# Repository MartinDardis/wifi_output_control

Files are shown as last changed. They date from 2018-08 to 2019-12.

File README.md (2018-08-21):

# Control de salidas - ESP8266 WiFi

## Caracteristicas Generales:

* Modo Station o Access Point automatico
* Soporte ARDUINO OTA y WEB OTA (update con firm.bin)
* Configuracion red WiFi y Login almacenada en memoria flash.
* Soporta hasta 2 salidas en simultaneo (PCB para 1 o 2).

## Diagrama de Cableado

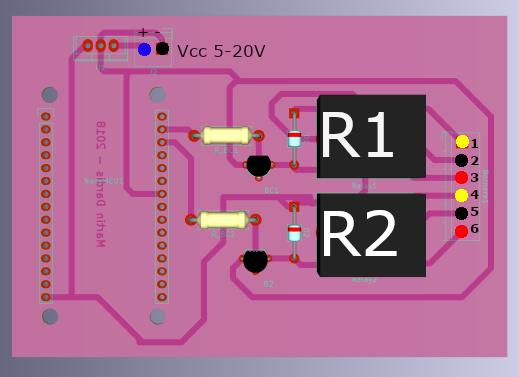
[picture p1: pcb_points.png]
PCB


Los pines **1,2,3** pertenecen al relay 1, donde 2 (NEGRO) es la entrada, 1 (AMARILLO) es la salida normal cerrada y 3 (ROJO) la normal abierta.

Los pines **4,5,6** pertenecen al relay 2, donde 5 (NEGRO) es la entrada, 4 (AMARILLO) es la salida normal cerrada y 6 (ROJO) la normal abierta.

Los pines de **VCC** (AZUL) y **GND** (NEGRO), pueden recibir entre 5 y 20 V. No deben ser utilizados si se alimenta el modulo mediante el puerto USB.

## Primer Uso

Una vez realizado el cableado se procede a la configuracion inicial.

1.  Una vez conectado, alimentar el circuito y esperar que el LED azul quede encendido fijo.
2.	Ya en modo AP, conectarse a la red del tip ESPXXX (XXX representa los ultimos numeros MAC del dispositivo).
3.	Mediante el navegador, ingresar a la pagina de control. http://192.168.4.1
4.	Ir a la pestaña Configuracion y ingresar los datos de la red que se quiere utilizar.
5. 	Reiniciar dispositivo. EL led comenzara a titilar, en caso de que pasado un tiempo no pueda conectarse volvera a encenderse fijo. Repetir la Configuracion. Si queda apagado la conexion tuvo exito.

Nota: El dispositivo admite conexion Serial USB, **Baudrate: 115200**

### TO DO

* Añadir mas salidas (Rediseño de PCB).
* Almacenar mas de un ssid a la vez.
* SPIFFS OTA
* Terminar el readme

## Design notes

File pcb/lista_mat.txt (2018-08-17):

1 bornera x 2pin
2 bornera x 3pin
1 lm7805
2 bc548
2 diodos (chicos)
2 Resistencias (220 ohm)
2 relay (5v cuadrados)

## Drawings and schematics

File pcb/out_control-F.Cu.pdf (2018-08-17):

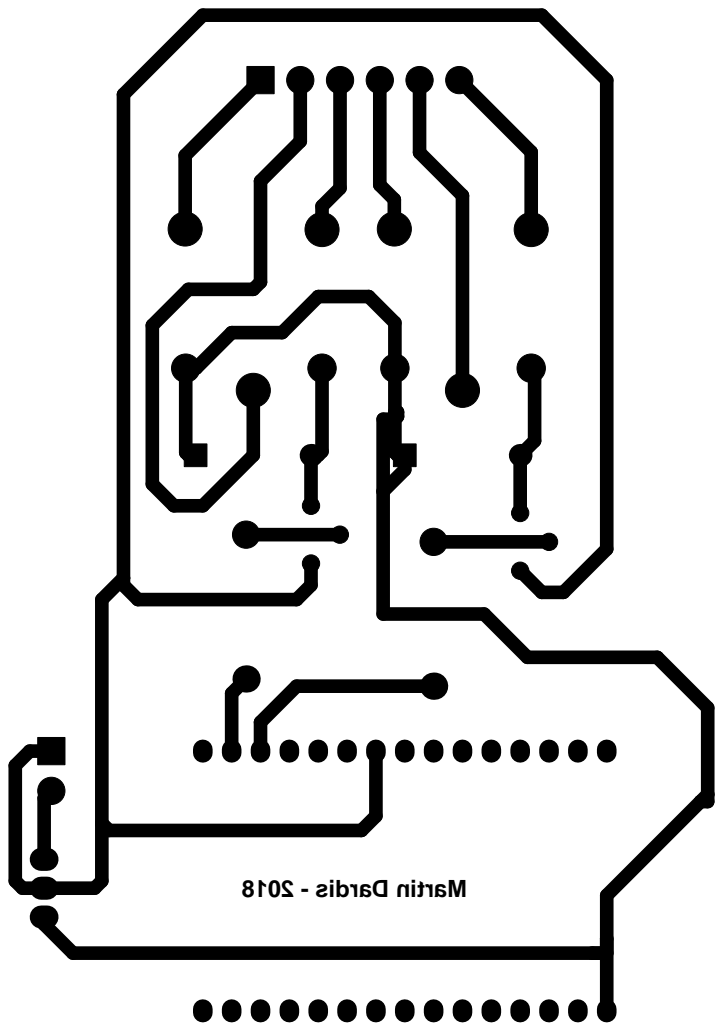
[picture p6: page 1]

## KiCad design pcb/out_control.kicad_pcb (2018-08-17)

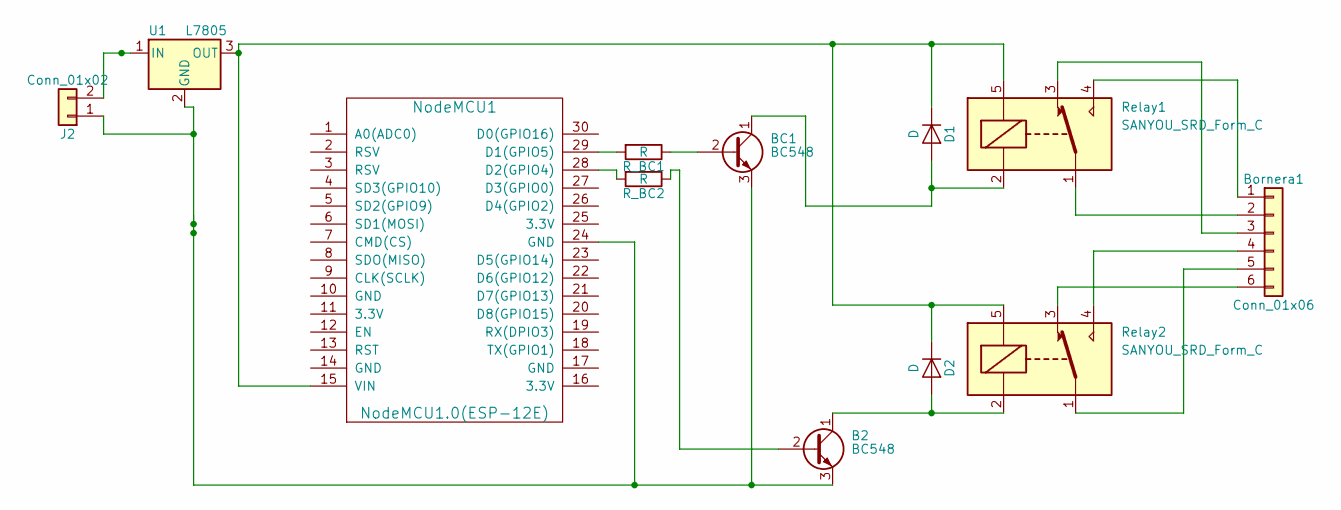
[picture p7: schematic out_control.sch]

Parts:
B2: BC548; TO-92_Molded_Wide
BC1: BC548; TO-92_Molded_Wide
Bornera1: Conn_01x06; TerminalBlock_4UCON_19963_06x3.5mm_Straight
D1, D2: D; D_T-1_P10.16mm_Horizontal
J2: Conn_01x02; TerminalBlock_4UCON_19963_02x3.5mm_Straight
NodeMCU1: NodeMCU1.0(ESP-12E); NodeMCU_Amica_R2
R_BC1, R_BC2: R; R_Axial_DIN0411_L9.9mm_D3.6mm_P12.70mm_Horizontal
Relay1, Relay2: SANYOU_SRD_Form_C; Relay_SPDT_SANYOU_SRD_Series_Form_C
U1: L7805; TO-220

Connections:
unnamed: B2.1 (C), D2.2 (A), Relay2.2
unnamed: B2.2 (B), R_BC2.1
unnamed: B2.3 (E), BC1.3 (E), J2.1, NodeMCU1.24 (GND), U1.2 (GND)
unnamed: BC1.1 (C), D1.2 (A), Relay1.2
unnamed: BC1.2 (B), R_BC1.1
unnamed: Bornera1.1, Relay1.4
unnamed: Bornera1.2, Relay1.1
unnamed: Bornera1.3, Relay1.3
unnamed: Bornera1.4, Relay2.4
unnamed: Bornera1.5, Relay2.1
unnamed: Bornera1.6, Relay2.3
unnamed: D1.1 (K), D2.1 (K), NodeMCU1.15 (VIN), Relay1.5, Relay2.5, U1.3 (OUT)
unnamed: J2.2, U1.1 (IN)
unnamed: NodeMCU1.28 (D2(GPIO4)), R_BC2.2
unnamed: NodeMCU1.29 (D1(GPIO5)), R_BC1.2

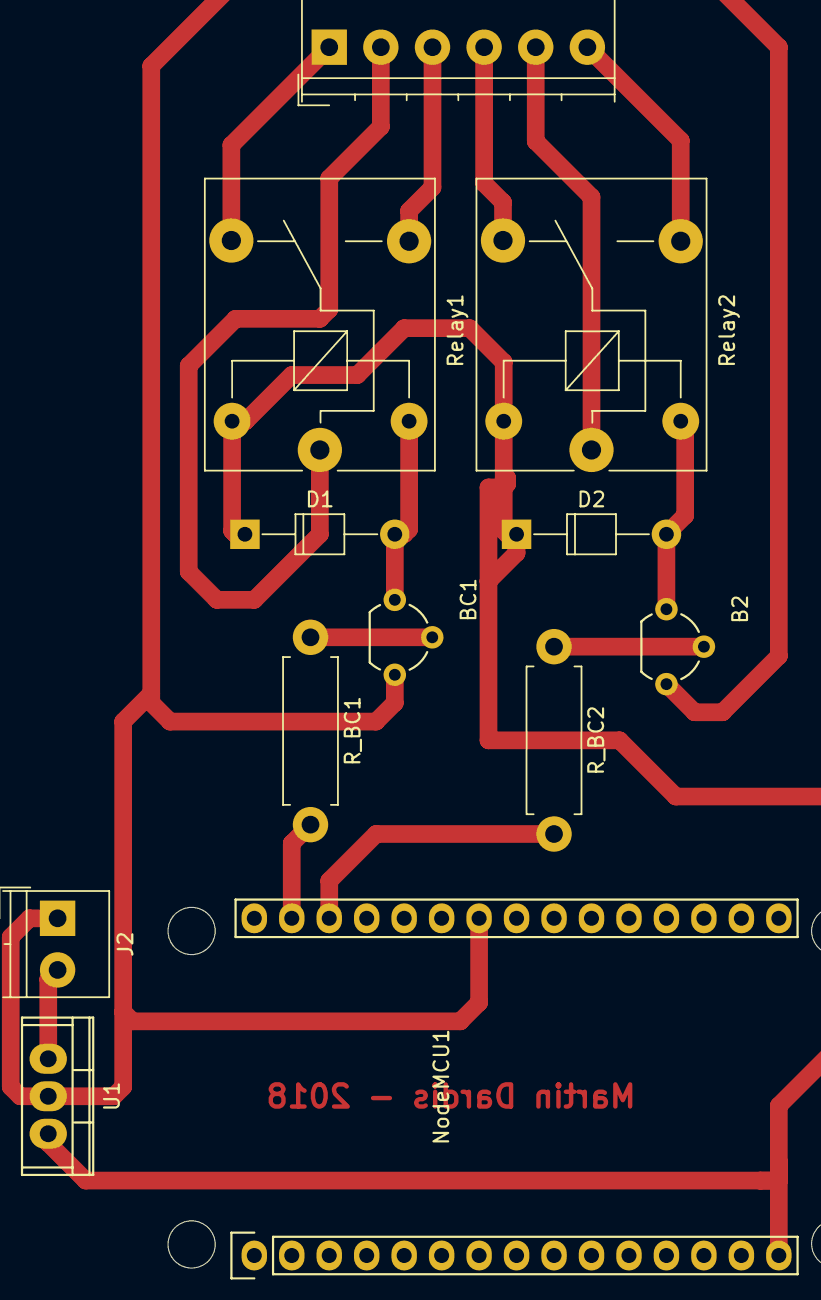
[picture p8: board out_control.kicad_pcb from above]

Board: 2 copper layers, 12 parts (0 on the bottom side), 15 nets.

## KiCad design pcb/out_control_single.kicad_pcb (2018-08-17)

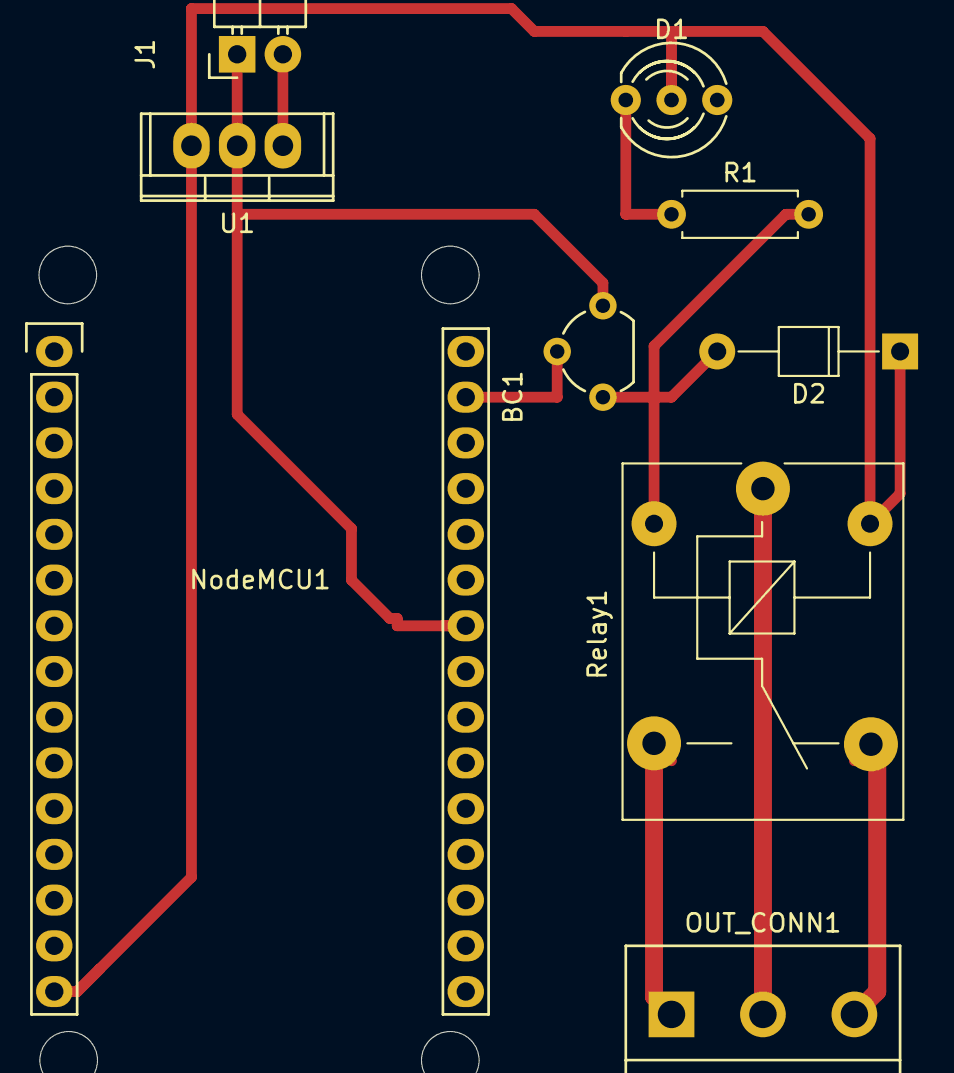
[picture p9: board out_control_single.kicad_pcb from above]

Board: 2 copper layers, 9 parts (0 on the bottom side), 9 nets.

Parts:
BC1: BC548; TO-92_Molded_Wide
D1: LED; LED-5MM-3
D2: D; D_T-1_P10.16mm_Horizontal
J1: Conn_01x02; Pin_Header_Angled_1x02
NodeMCU1: NodeMCU1.0(ESP-12E); NodeMCU_Amica_R2
OUT_CONN1: Conn_01x03; bornier3
R1: R; R_Axial_DIN0207_L6.3mm_D2.5mm_P7.62mm_Horizontal
Relay1: SANYOU_SRD_Form_C; Relay_SPDT_SANYOU_SRD_Series_Form_C
U1: L7805; TO-220

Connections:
unnamed: BC1.1, D2.2, R1.2, Relay1.2
unnamed: BC1.2, NodeMCU1.29
unnamed: BC1.3, J1.1, NodeMCU1.24, U1.2
unnamed: D1.1, R1.1
unnamed: D1.2, D2.1, NodeMCU1.15, Relay1.5, U1.3
unnamed: J1.2, U1.1
unnamed: OUT_CONN1.1, Relay1.3
unnamed: OUT_CONN1.2, Relay1.1
unnamed: OUT_CONN1.3, Relay1.4

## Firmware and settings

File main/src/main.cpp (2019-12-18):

#include <WiFiUdp.h>
#include <ESP8266WiFi.h>
#include <ESP8266WebServer.h>
#include <WiFiClient.h>
#include <ESP8266HTTPUpdateServer.h>
#include <ESP8266mDNS.h>


#include "FS.h"   // Include the SPIFFS library
#include "libs/WebServerHandlers.h"
#include "config.h"
#include "libs/OTA.h"

bool gpio1_state=false;
bool gpio0_state=false;

ESP8266WebServer server(80);
ESP8266HTTPUpdateServer httpUpdater;
const int WAIT_TIME = WAIT_TIME_CT; //Time (in seconds) to wait wifi before enable AP mode
String USERNAME = USERNAME_CT;//Default username
String PASSWORD = PASSWORD_CT;//Default password
bool logged = LOGGED; //Init without logged session
char* WEB_OTA_NAME = WEB_OTA_NAME_CT;//Default changes with username to login
char* WEB_OTA_PASS = WEB_OTA_PASS_CT; //Default changes with password to login

void initMDNS();

void setup() {
  Serial.begin(SERIAL_SPEED);         
  Serial.println('\n');
  delay(1000);
  Serial.print("\nESP8266 OUT CONTROL - MARTIN DARDIS 2018\n");
  pinMode(LED_BUILTIN,OUTPUT);
  pinMode(GPIO0,OUTPUT);
  pinMode(GPIO1,OUTPUT);
  if( digitalRead(GPIO0) == HIGH)
    gpio0_state = true;
  if( digitalRead(GPIO1) == HIGH)
    gpio0_state = true;
  startFS();
  read_login_config();
  startWiFi();
  startOTA();
  initMDNS();
  startServer();
  Serial.print("\n READY. SERVER REQUESTs \n");
}

void loop(void) {
  ArduinoOTA.handle();
  server.handleClient();
  if(logged){
    String gp0=server.arg("gpio0");
    if (gp0 == "ON" && !gpio0_state){
      Serial.println("GPIO 0 = ON" );
      digitalWrite(GPIO0, HIGH);
      gpio0_state = true;
    }
    else if (gp0 == "OFF" && gpio0_state){
      Serial.println("GPIO 0 = OFF");
      digitalWrite(GPIO0, LOW);
      gpio0_state = false;
    }
    String gp1=server.arg("gpio1");
    if (gp1 == "ON" && !gpio1_state){
      Serial.println("GPIO 1 = ON" );
      digitalWrite(GPIO1, HIGH);
      gpio1_state = true;
    }
    else if (gp1 == "OFF" && gpio1_state){
      Serial.println("GPIO 1 = OFF");
      digitalWrite(GPIO1, LOW);
      gpio1_state = false;
    }
  }
}

void initMDNS(){
  if (!MDNS.begin(mDNS)) {             
     Serial.println("Error iniciando mDNS");
     return;
  }
  Serial.print("mDNS iniciado: ");
  Serial.print(mDNS);
  Serial.print(".local\n");
}
